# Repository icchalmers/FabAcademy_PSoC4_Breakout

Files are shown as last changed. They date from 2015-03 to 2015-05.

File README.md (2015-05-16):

# FabAcademy_PSoC4_Breakout

A small breakout board for the PSoC 4 CY8CKIT-049 42xx prototyping kit. It includes WS2812b LEDs, a TMP275 temperature sensor, CapSense buttons and a header to attach an ESP-01 module. It was made as part [Fab Academy 2015](http://www.fabacademy.org/) at [Fab Lab Strathclyde](http://www.strath.ac.uk/fablab/). You can follow the process on [my class website](http://fabacademy.org/archives/2015/eu/students/chalmers.iain/index.html). The content is also mirrored to [my GitHub Pages site](http://icchalmers.github.io/).

Note that there is one jumper wire needed if making this as a single sided board.

# WARNING!

This board runs at 3.3V. You MUST modify the USB-UART board that comes with the kit or bad things will happen! The simplest option is to remove the fuse on VUSB and power everything from the board. More options are discussed on my class webpage.

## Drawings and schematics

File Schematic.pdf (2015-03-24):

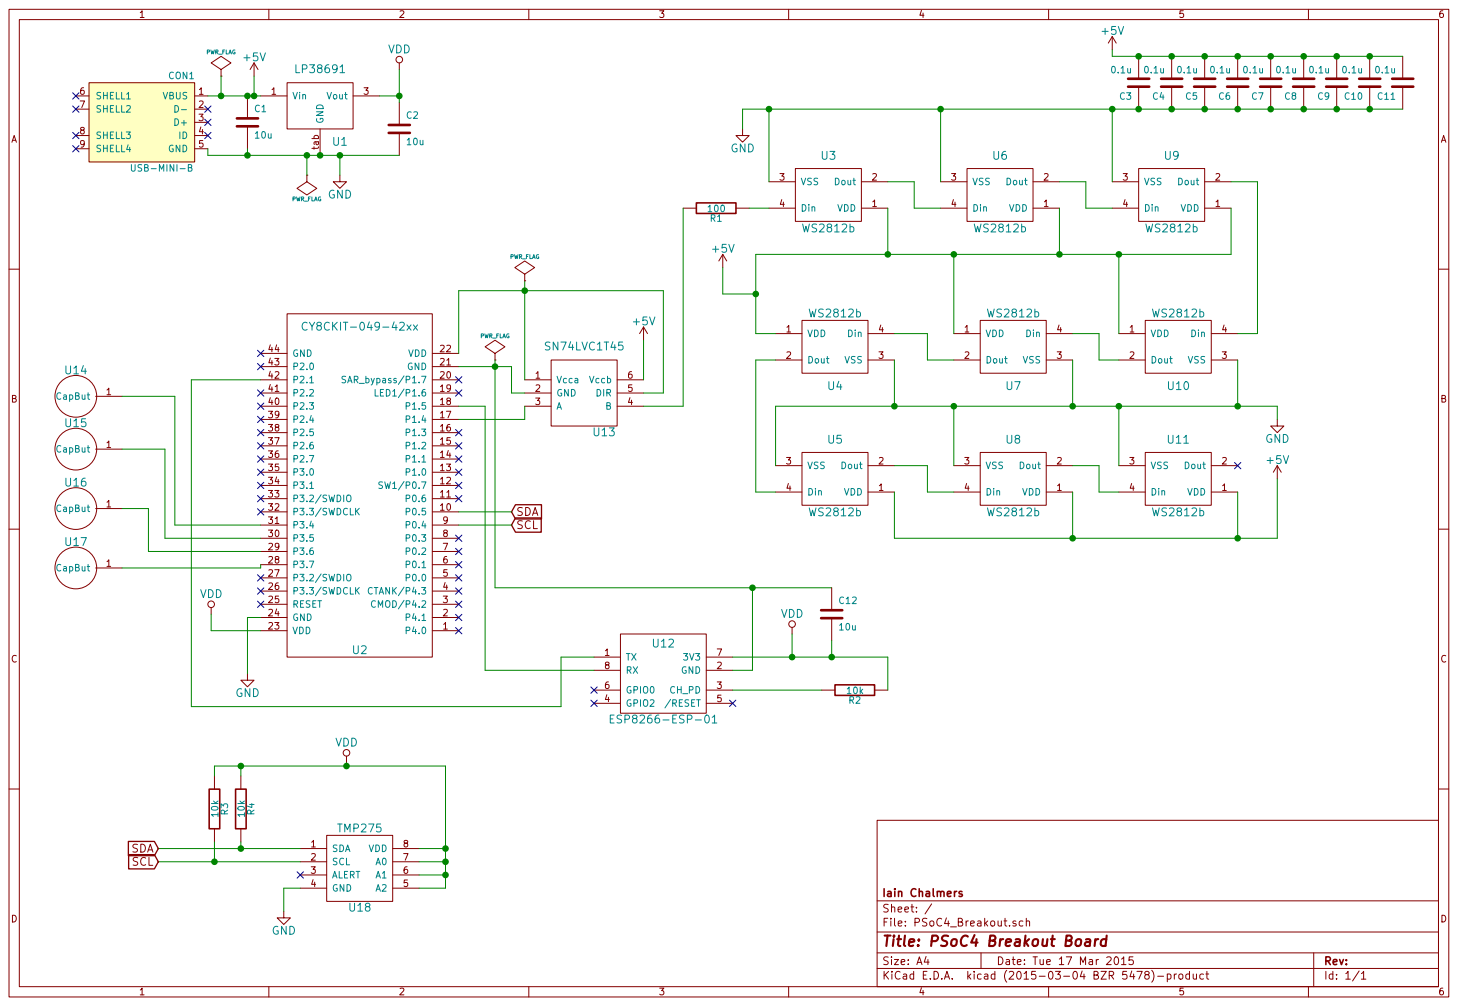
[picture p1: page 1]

File: PSoC4_Breakout.sch Sheet: /
Id: 1/1 Title: PSoC4 Breakout Board

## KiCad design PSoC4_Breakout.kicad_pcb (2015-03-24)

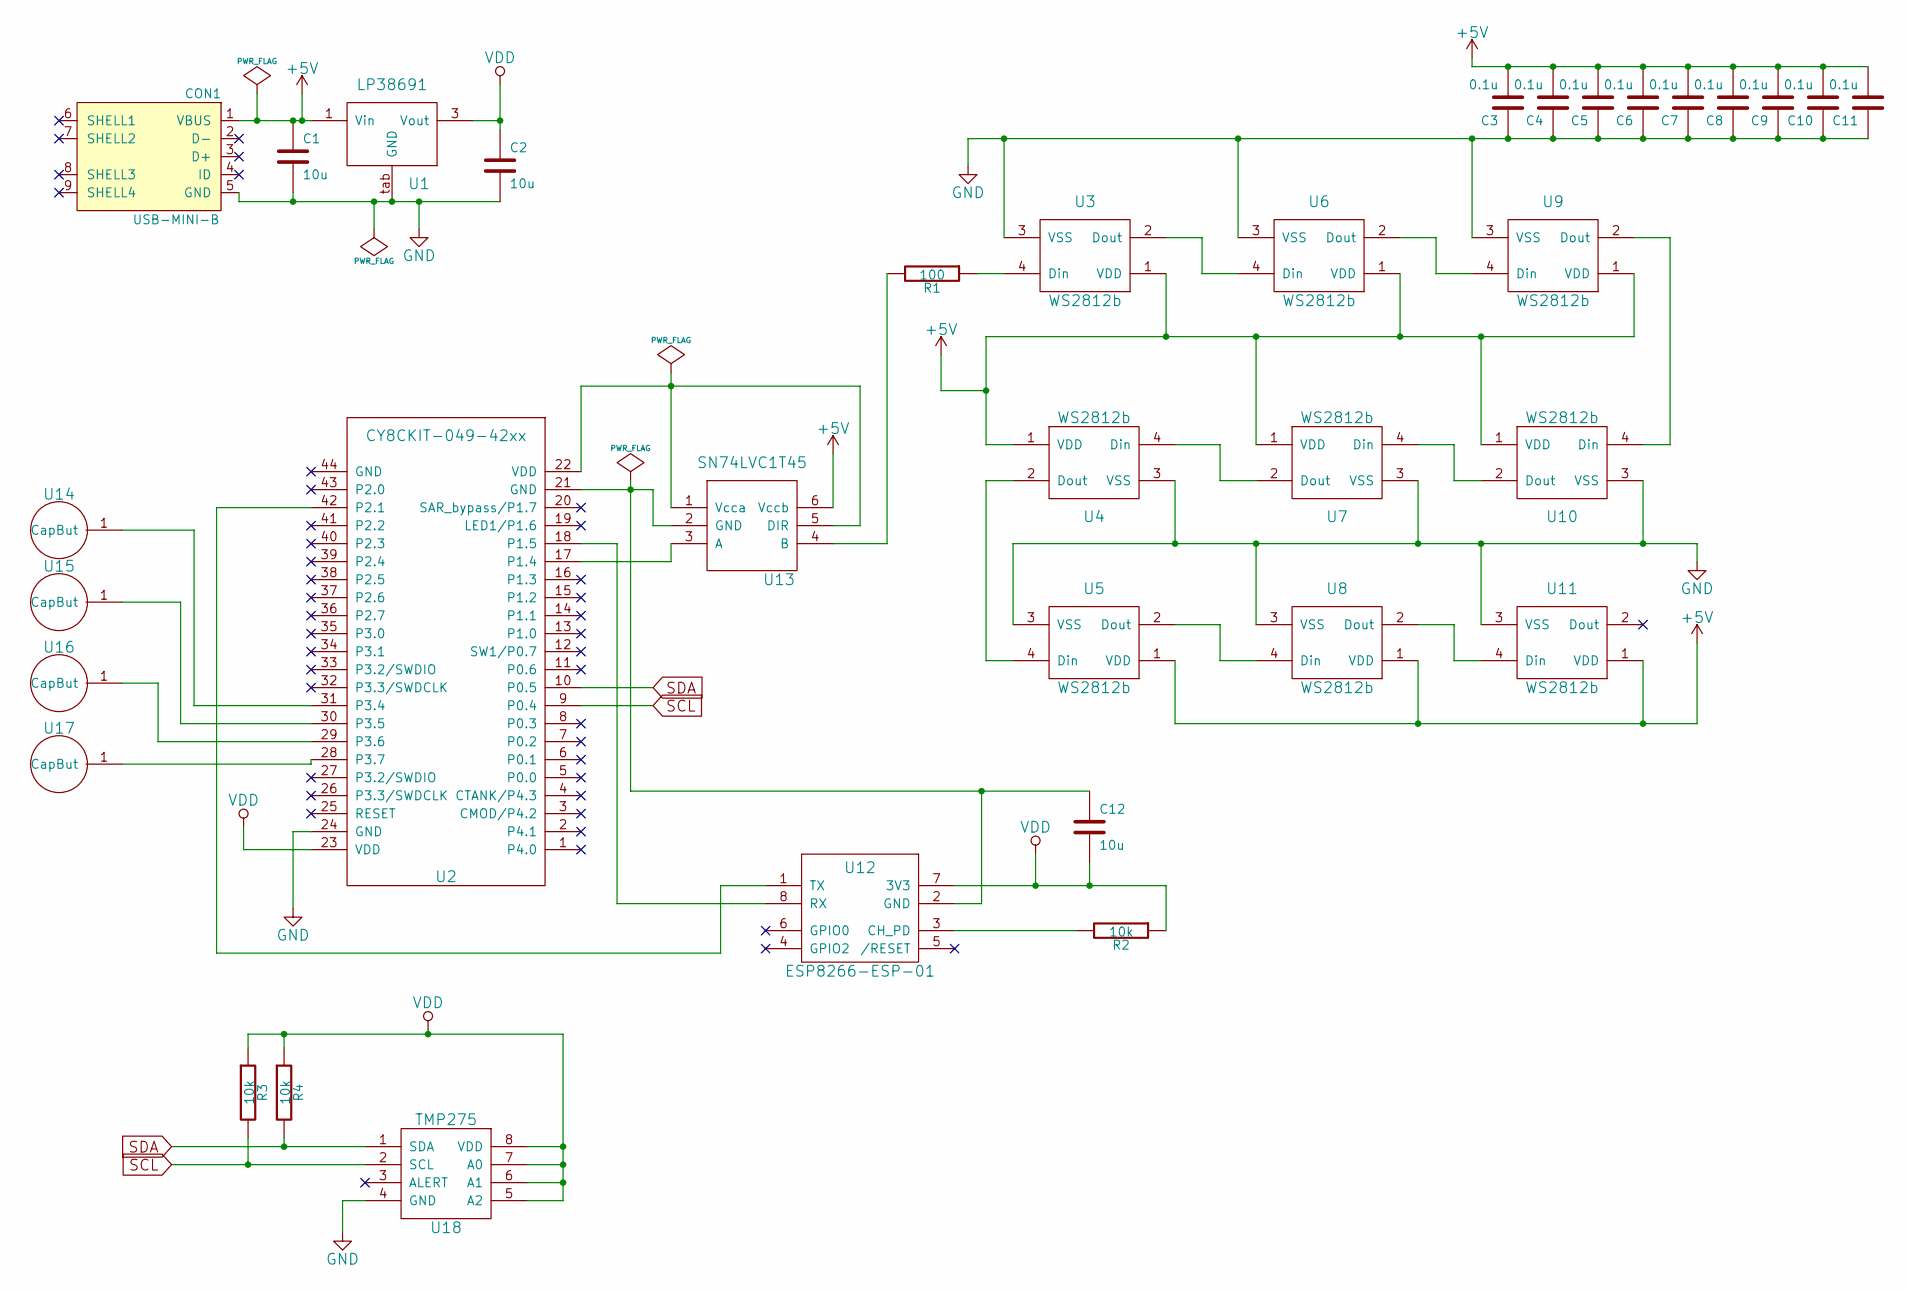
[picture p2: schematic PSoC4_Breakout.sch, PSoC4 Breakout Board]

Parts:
C1, C2, C12: 10u; C_1206_HandSoldering_IainEdit
C3, C4, C5, C6, C7, C8, C9, C10, C11: 0.1u; C_1206_HandSoldering_IainEdit
CON1: USB-MINI-B; conn_usb_B_mini_smd
R1: 100; C_1206_HandSoldering_IainEdit
R2, R3, R4: 10k; C_1206_HandSoldering_IainEdit
U1: LP38691; LP38691_TO252
U2: CY8CKIT-049-42xx; CYKIT-49-42xx
U3, U4, U5, U6, U7, U8, U9, U10, U11: WS2812b; WS2812b_handsolder
U12: ESP8266-ESP-01
U13: SN74LVC1T45; TI-DBV-SOT23_handsolder
U14, U15, U16, U17: CapSenseButton
U18: TMP275; TI-D-SO-8_handsolder

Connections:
+5V: C1.1, C3.2, C4.2, C5.2, C6.2, C7.2, C8.2, C9.2, C10.2, C11.2, CON1.1 (VBUS), U1.1 (Vin), U3.1 (VDD), U4.1 (VDD), U5.1 (VDD), U6.1 (VDD), U7.1 (VDD), U8.1 (VDD), U9.1 (VDD), U10.1 (VDD), U11.1 (VDD), U13.6 (Vccb)
GND: C1.2, C2.2, C3.1, C4.1, C5.1, C6.1, C7.1, C8.1, C9.1, C10.1, C11.1, CON1.5 (GND), U1.tab (GND), U2.24 (GND), U3.3 (VSS), U4.3 (VSS), U5.3 (VSS), U6.3 (VSS), U7.3 (VSS), U8.3 (VSS), U9.3 (VSS), U10.3 (VSS), U11.3 (VSS), U18.4 (GND)
unnamed: C12.1, U2.21 (GND), U12.2 (GND), U13.2 (GND)
unnamed: R1.1, U3.4 (Din)
unnamed: R1.2, U13.4 (B)
unnamed: R2.2, U12.3 (CH_PD)
unnamed: U3.2 (Dout), U6.4 (Din)
unnamed: U4.2 (Dout), U5.4 (Din)
unnamed: U4.4 (Din), U7.2 (Dout)
unnamed: U5.2 (Dout), U8.4 (Din)
unnamed: U6.2 (Dout), U9.4 (Din)
unnamed: U7.4 (Din), U10.2 (Dout)
unnamed: U9.2 (Dout), U10.4 (Din)
unnamed: U8.2 (Dout), U11.4 (Din)
unnamed: U2.42 (P2.1), U12.1 (TX)
unnamed: U2.18 (P1.5), U12.8 (RX)
unnamed: U2.22 (VDD), U13.1 (Vcca), U13.5 (DIR)
unnamed: U2.17 (P1.4), U13.3 (A)
unnamed: U2.31 (P3.4), U14.1
unnamed: U2.30 (P3.5), U15.1
unnamed: U2.29 (P3.6), U16.1
unnamed: U2.28 (P3.7), U17.1
SCL: R3.2, U2.9 (P0.4), U18.2 (SCL)
SDA: R4.2, U2.10 (P0.5), U18.1 (SDA)
VDD: C2.1, C12.2, R2.1, R3.1, R4.1, U1.3 (Vout), U2.23 (VDD), U12.7 (3V3), U18.5 (A2), U18.6 (A1), U18.7 (A0), U18.8 (VDD)

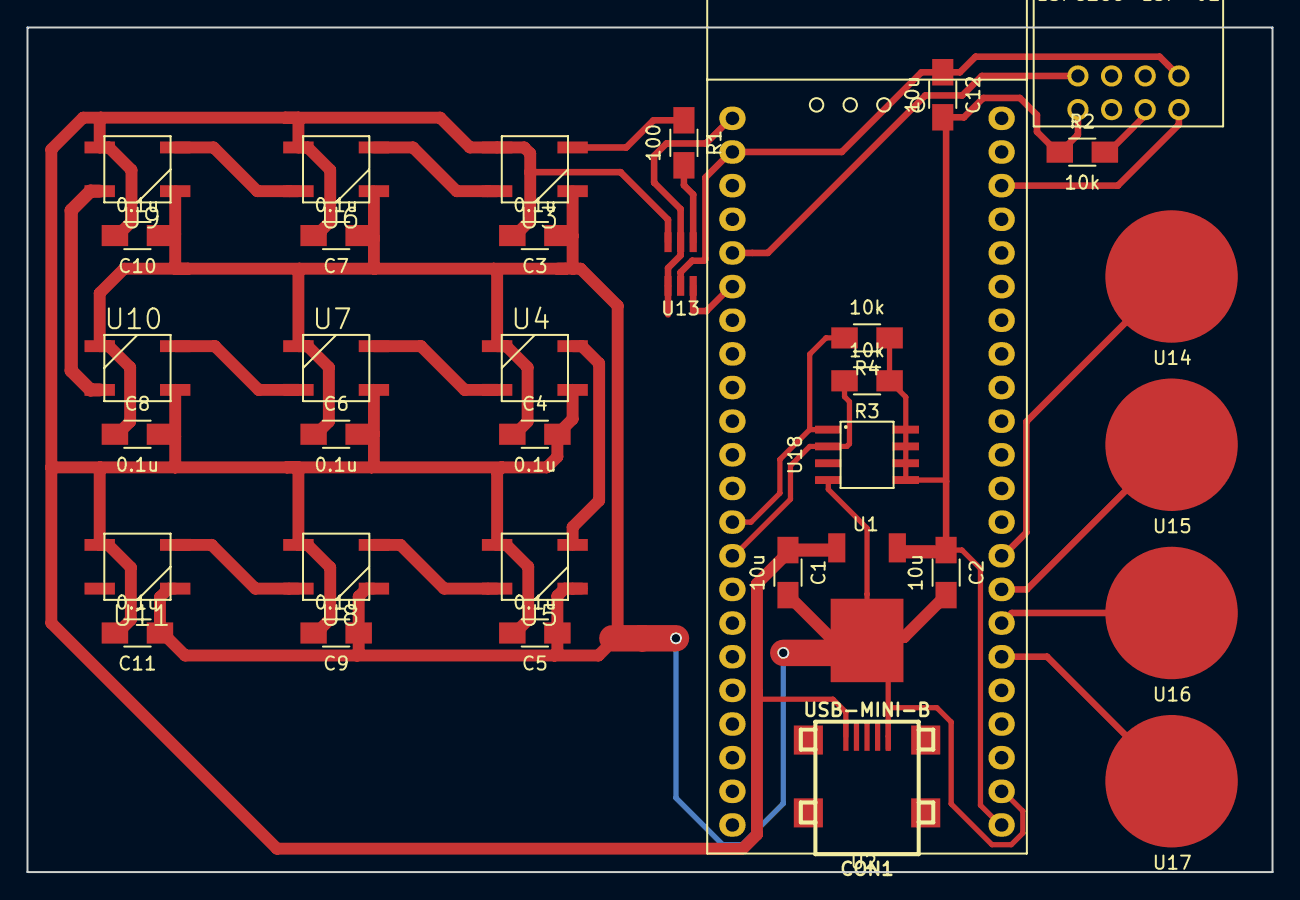
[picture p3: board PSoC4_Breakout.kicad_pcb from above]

Board: 2 copper layers, 94.0 x 63.8 mm, 35 parts (0 on the bottom side), 25 nets.
